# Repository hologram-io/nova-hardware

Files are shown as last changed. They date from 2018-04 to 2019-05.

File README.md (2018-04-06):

# Hologram Nova Hardware Repository

The Hologram Nova is an Open-Sourced USB Cellular Modem utilizing the [ublox SARA](https://www.u-blox.com/en/product-search/field_product_form/sara-111) family of modems.

Certified by the Open Source Hardware Association - [Certificate US000077](http://certificate.oshwa.org/certification-directory/)

We're excited to see what you'll build with these designs. If you require support for integrating these designs into your project, you can reach out to Hologram Solutions Engineering at sales@hologram.io to learn about Hologram design review services or hear about our engineering design partners.

### Additional Nova Information

 - [Nova Product Page](https://hologram.io/nova/)
 - [Nova User Manual](https://hologram.io/docs/docs/reference/nova/user-manual/)
 - [Nova Datasheet](https://hologram.io/docs/reference/nova/datasheet/)

### Additional ublox SARA Documentation

**2G/3G - U200 series**
 - [SARA-U2 System Integration Manual](https://www.u-blox.com/sites/default/files/SARA-G3-U2_SysIntegrManual_%28UBX-13000995%29_0.pdf)
 - [u-blox AT Commands Manual](https://www.u-blox.com/sites/default/files/u-blox-CEL_ATCommands_%28UBX-13002752%29.pdf)
 - [AT Command Examples for u-blox cellular modules](https://www.u-blox.com/sites/default/files/AT-CommandsExamples_AppNote_%28UBX-13001820%29.pdf)
 - [Multiplexer implementation in cellular modules](https://www.u-blox.com/sites/default/files/products/documents/MuxImplementation_ApplicationNote_%28UBX-13001887%29.pdf)
 
**LTE Cat M1/NB1 and EGPRS - R400/N400 series**

 - [SARA-R4 System Integration Manual](https://www.u-blox.com/sites/default/files/SARA-R4_SysIntegrManual_%28UBX-16029218%29.pdf)
 - [SARA-R4 AT Commands Manual](https://www.u-blox.com/sites/default/files/SARA-R4_ATCommands_%28UBX-17003787%29.pdf)

**Power-optimized NB-IoT - N200 series**

 - [SARA-N2 System Integration Manual](https://www.u-blox.com/sites/default/files/SARA-N2_SysIntegrManual_%28UBX-17005143%29.pdf)
 - [SARA-N2 AT Commands](https://www.u-blox.com/sites/default/files/SARA-N2_ATCommands_%28UBX-16014887%29.pdf)

### Additional Hologram Information

 - [BLOG Why We Open Source Hardware](https://hologram.io/open-sourcing-our-hardware/)
 - [Documentation](https://hologram.io/docs/)
 - [Forums](https://community.hologram.io/)

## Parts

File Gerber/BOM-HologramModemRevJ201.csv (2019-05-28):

LibRef | Internal PN | Quantity | Designator | Description | Footprint | Comment | MFG | MPN
ANT-A-1JB | CON-0006 | 1 | ANT_UFL |  | UFL | ANT-A-1JB | Amphenol | A-1JB
CAP0.1uF_0402 | CAP-0004 | 3 | C2, C6, C48 | CAPACITOR, American symbol | CAP0402 | 0.1 uF | MURATA | GRM155R61C104KA88D
CAP2.2uF_0603 | CAP-0002 | 1 | C11 | Ceramic Capacitor SMD | CAP0603 | 2.2 uF | SAMSUNG | CL10A225MQ8NNNC
CAP10nF_0402 | CAP-0016 | 3 | C1, C5, C39 | CAPACITOR, American symbol | CAP0402 | 10 nF | MURATA | GRM155R71C103KA01D
CAP10uF_0603 | CAP-0007 | 1 | C34 | Ceramic Capacitor SMD | CAP0603 | 10 uF | Murata | GRM188R60J106ME84D
CAP15pF_0402 | CAP-0011 | 3 | C4, C8, C46 | CAPACITOR, American symbol | CAP0402 | 15 pf | AVX/ELCO | 04025A150JAT2A
CAP22uF_0603 | CAP-0008 | 3 | C36, C37, C38 | Ceramic Capacitor SMD | CAP0603 | 22 uF | MURATA | GRM188R60J226MEA0D
CAP47pf_0402 | CAP-0010 | 4 | C41, C42, C44, C45 | CAPACITOR, American symbol | CAP0402 | 47 pF | AVX | 04025A470JAT2A
CAP56pF_0402 | CAP-0009 | 3 | C3, C7, C40 | CAPACITOR, American symbol | CAP0402 | 56 pf | KEMET | C0402C560J5GACTU
CAP330uF_1210P | CAP-0012 | 3 | C47, C49, C50 | Capacitor | CAP1210POL | 330uF | AVX | F950J337MBAAQ2
FerriteBead_120ohm_3A | IND-0005 | 1 | L7 |  | RES0603 | FerriteBead 120ohm, 3A | Murata | BLM18KG121TN1D
INDUCTOR_1UH_XFL4020-102MEC | IND-0003 | 1 | L5 |  | COILCRAFT_XFL4020 | 1uH | Coilcraft | XFL4020-102MEC
LED_0402_VLMB | DIO-0007 | 1 | D1 | LED, Vishay Blue 0402 | LED_0402_VISHAY_VLMB | LED_0402_VLMB | VISHAY | VLMB1500-GS08
LED_0402_VLMS | DIO-0008 | 1 | D2 | LED, Vishay Red 0402 | LED_0402_VISHAY_VLMS | LED_0402_VLMS | VISHAY | VLMS1500-GS08
PESD_14V | DIO-0009 | 7 | D3, D4, D5, D6, D7, D8, D9 | DIODE,ZENER VOLTAGE SUPPRESSOR,+/-14V | PESD_0402 |  | Littlefuse | PESD0402-140
RES0R_0603 | RES-0020 | 1 | L1 | Resistor, 0 ohm, 0603 case | RES0603 | 0 ohm | YAEGO | RC0603JR-070RL
RES1M_0402 | RES-0014 | 1 | R13 | Resistor, 1M ohm, 0402 case, 1% | RES0402 | 1M | YAEGO | RC0402FR-071ML
RES3K_0402 | RES-0019 | 2 | R3, R5 | Resistor, 3K ohm, 0402 case, 1% | RES0402 | 3k | YAEGO | RC0402FR-073KL
RES10K_0402 | RES-0008 | 4 | R4, R6, R7, R8 | Resistor, 10k ohm, 0402 | RES0402 | 10K | YAEGO | RC0402JR-0710KL
RES22R_0402 | RES-0016 | 2 | R1, R2 | Resistor, 22 ohm, 0402 case, 1% | RES0402 | 22 | YAEGO | RC0402FR-0722RL
RES100K_0402 | RES-0003 | 1 | R51 | Resistor, 100k ohm, 0402 | RES0402 | 100K | PANASONIC | ERJ-2GEJ104X
RES150K_0402 | RES-0004 | 1 | R12 | Res, 150k ohm, 0402 case, 1% | RES0402 | 150k | YAEGO | RC0402FR-07150KL
RES470R_0402 | RES-0006 | 1 | R9 | Resistor, 470 ohm, 0402 case, 1% | RES0402 | 470 | PANASONIC | ERJ-2GEJ471X
SARA-U2XX | IC-0007 | 1 | U16 |  | SARA | SARA-U2XX | U-BLOX | SARA-U201-03B
SIM_CARD_NANO | CON-0007 | 1 | SIM1 |  | SIM_CARD_NANO | SIM_CARD_NANO | GLOBAL CONNECTOR TECHNOLOGY | SIM8050-6-0-14-01-A
TPS63020 | IC-0013 | 1 | U2 | Regulator, Boost Buck, 3A | QFN-14-POWERPAD3X4DSJ | TPS63020 | TI | TPS63020DSJ
TSTR_3904_SOT23 | IC-0014 | 4 | Q1, Q2, Q3, Q4 | TSTR,NPN 3904, SOT23 | SOT23 |  | ON Semiconductor | MMBT3904LT1G
USB_A_PLUG_MOLEX_0480372200 | CON-0008 | 1 | J1 | Connector, USB A, Plug, 0480372200 | USB_A_PLUG_MOLEX_0480372200 - clipped_copper | USB_A_PLUG_MOLEX_0480372200 | MOLEX | 480372200

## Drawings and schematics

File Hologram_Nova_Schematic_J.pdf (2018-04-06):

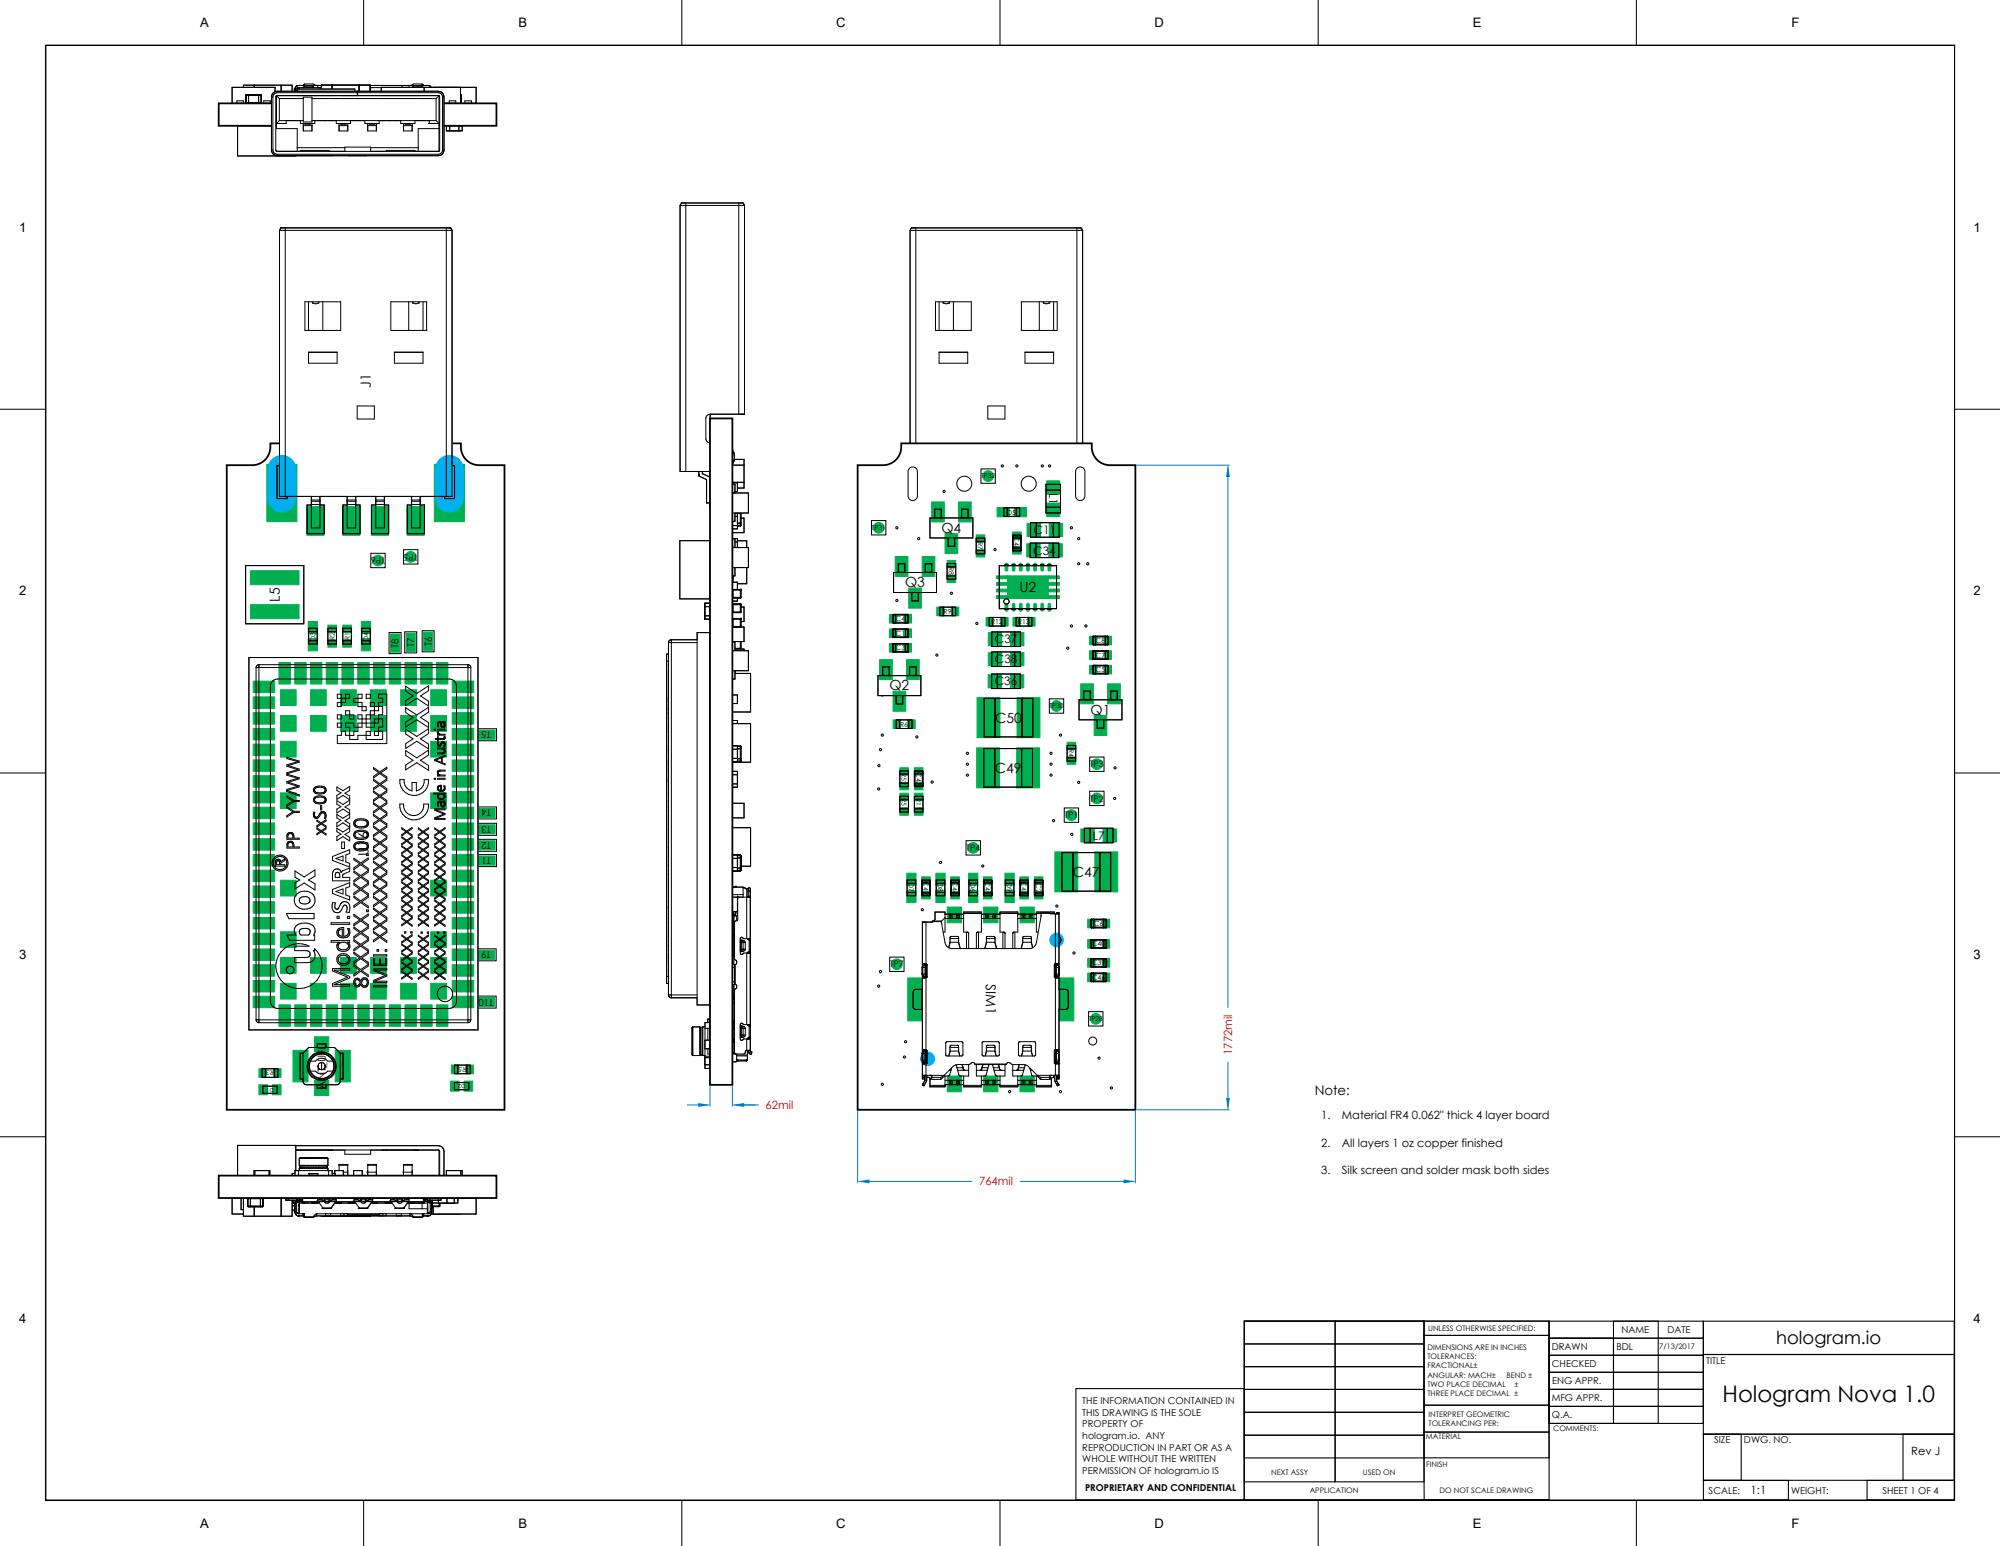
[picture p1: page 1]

1. Material FR4 0.062" thick 4 layer board

2. All layers 1 oz copper finished

3. Silk screen and solder mask both sides

UNLESS OTHERWISE SPECIFIED: | | NAME | DATE 7/13/2017 | hologram.io
DIMENSIONS ARE IN INCHES TOLERANCES: FRACTIONAL± ANGULAR: MACH± BEND ± TWO PLACE DECIMAL ± THREE PLACE DECIMAL ± | DRAWN | BDL

CHECKED | | | TITLE Hologram Nova 1.0
ENG APPR.

THE INFORMATION CONTAINED IN THIS DRAWING IS THE SOLE PROPERTY OF hologram.io. ANY REPRODUCTION IN PART OR AS A WHOLE WITHOUT THE WRITTEN PERMISSION OF hologram.io IS PROPRIETARY AND CONFIDENTIAL | | | MFG APPR.

INTERPRET GEOMETRIC TOLERANCING PER: | Q.A.

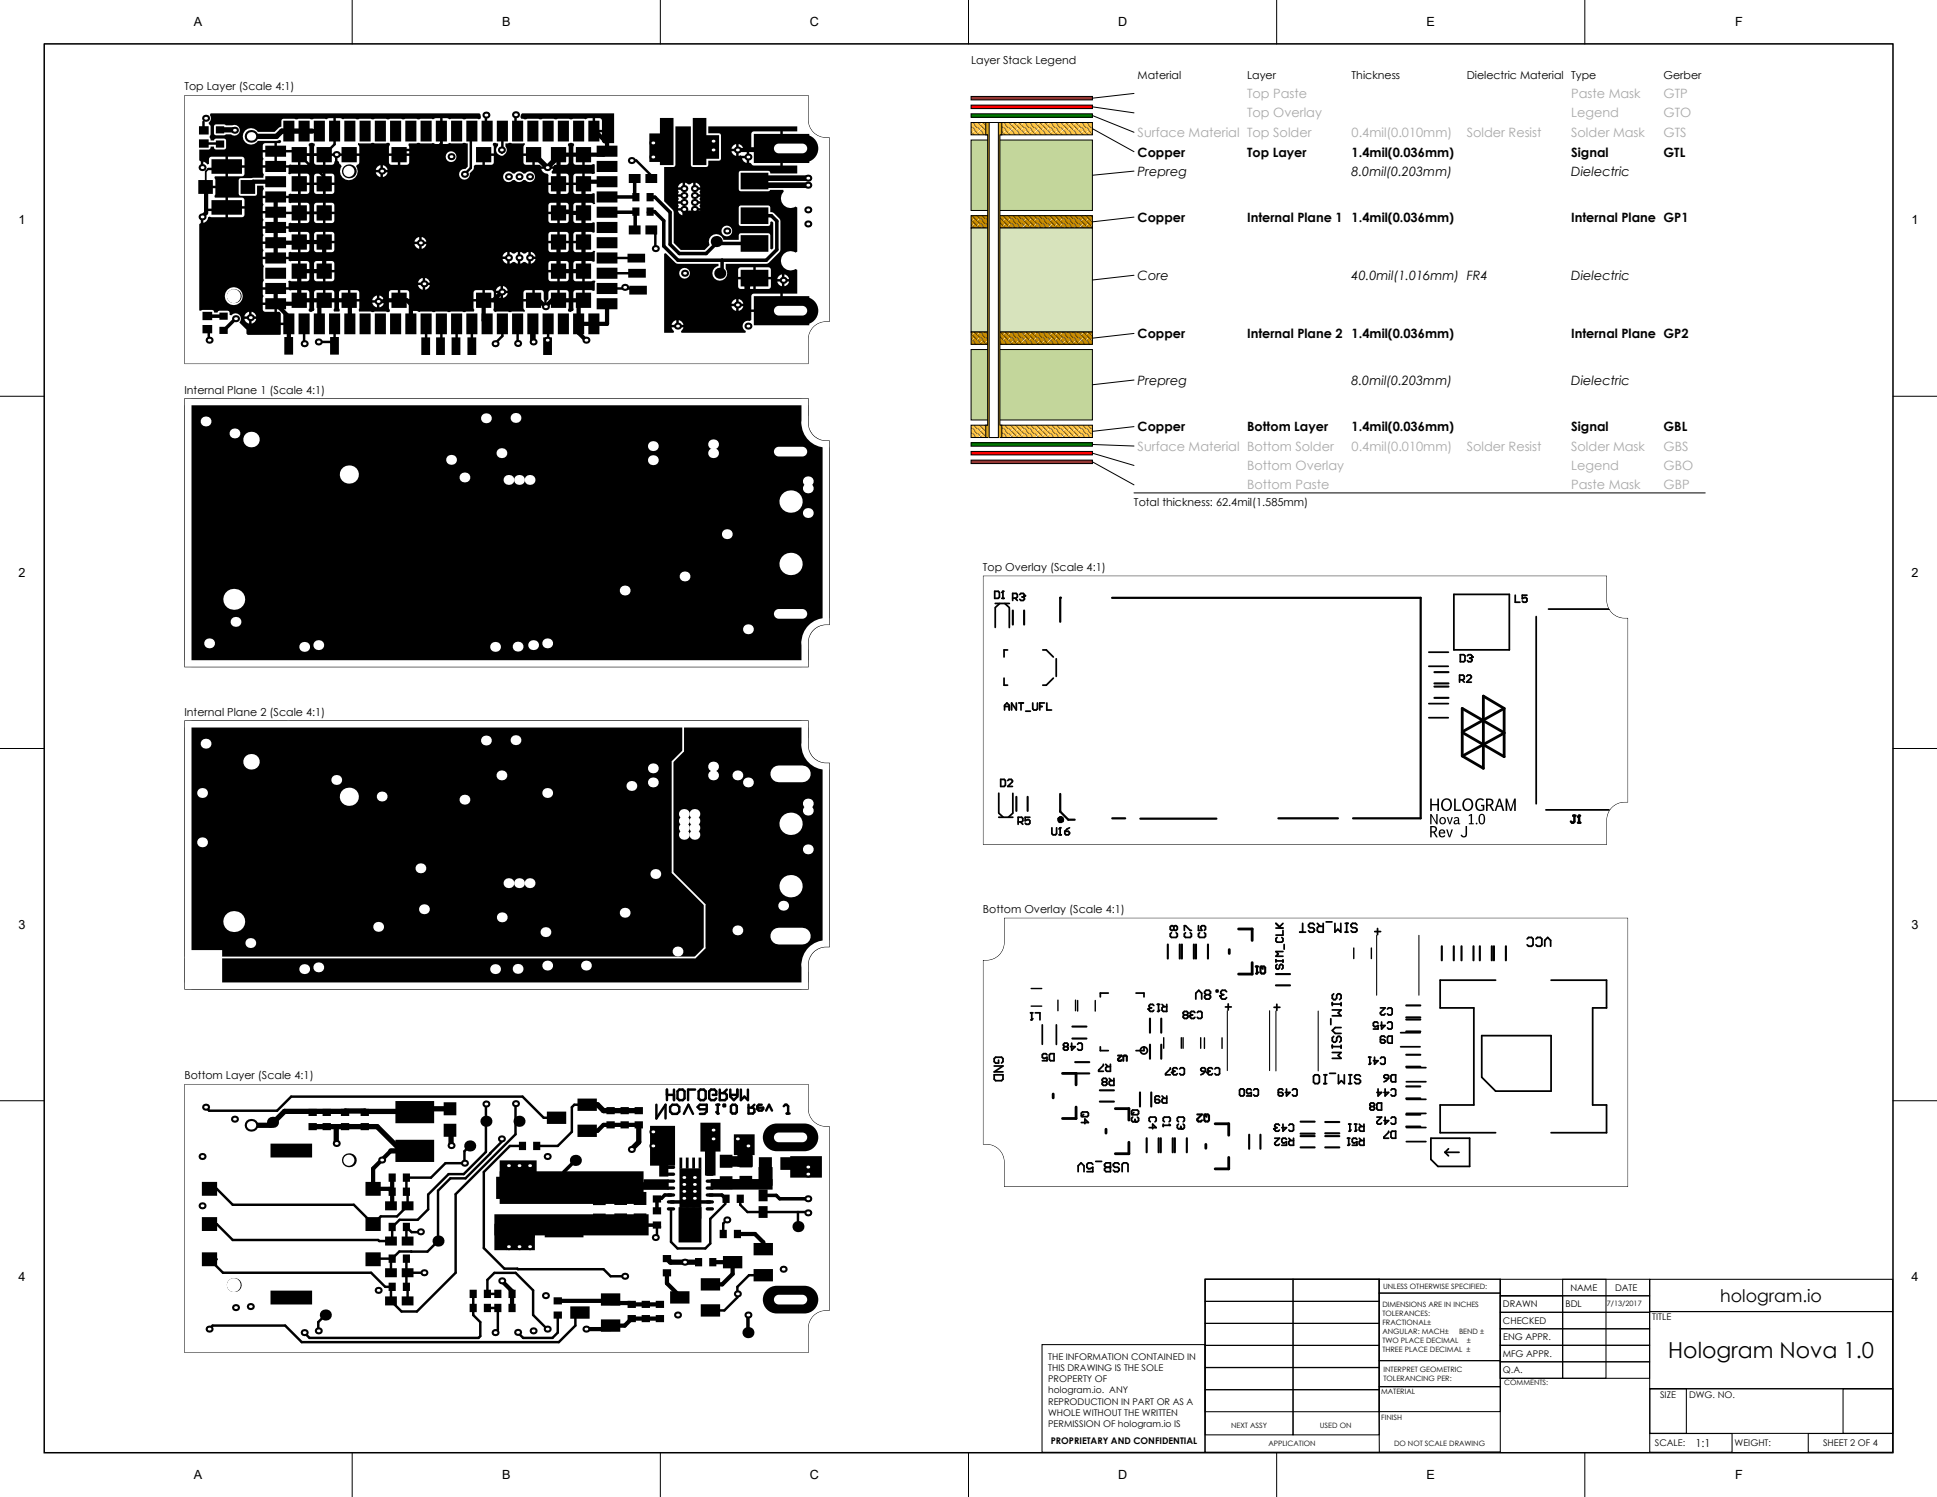
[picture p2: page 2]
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

CHECKED | | | TITLE Hologram Nova 1.0
ENG APPR.

THE INFORMATION CONTAINED IN THIS DRAWING IS THE SOLE | | | MFG APPR.

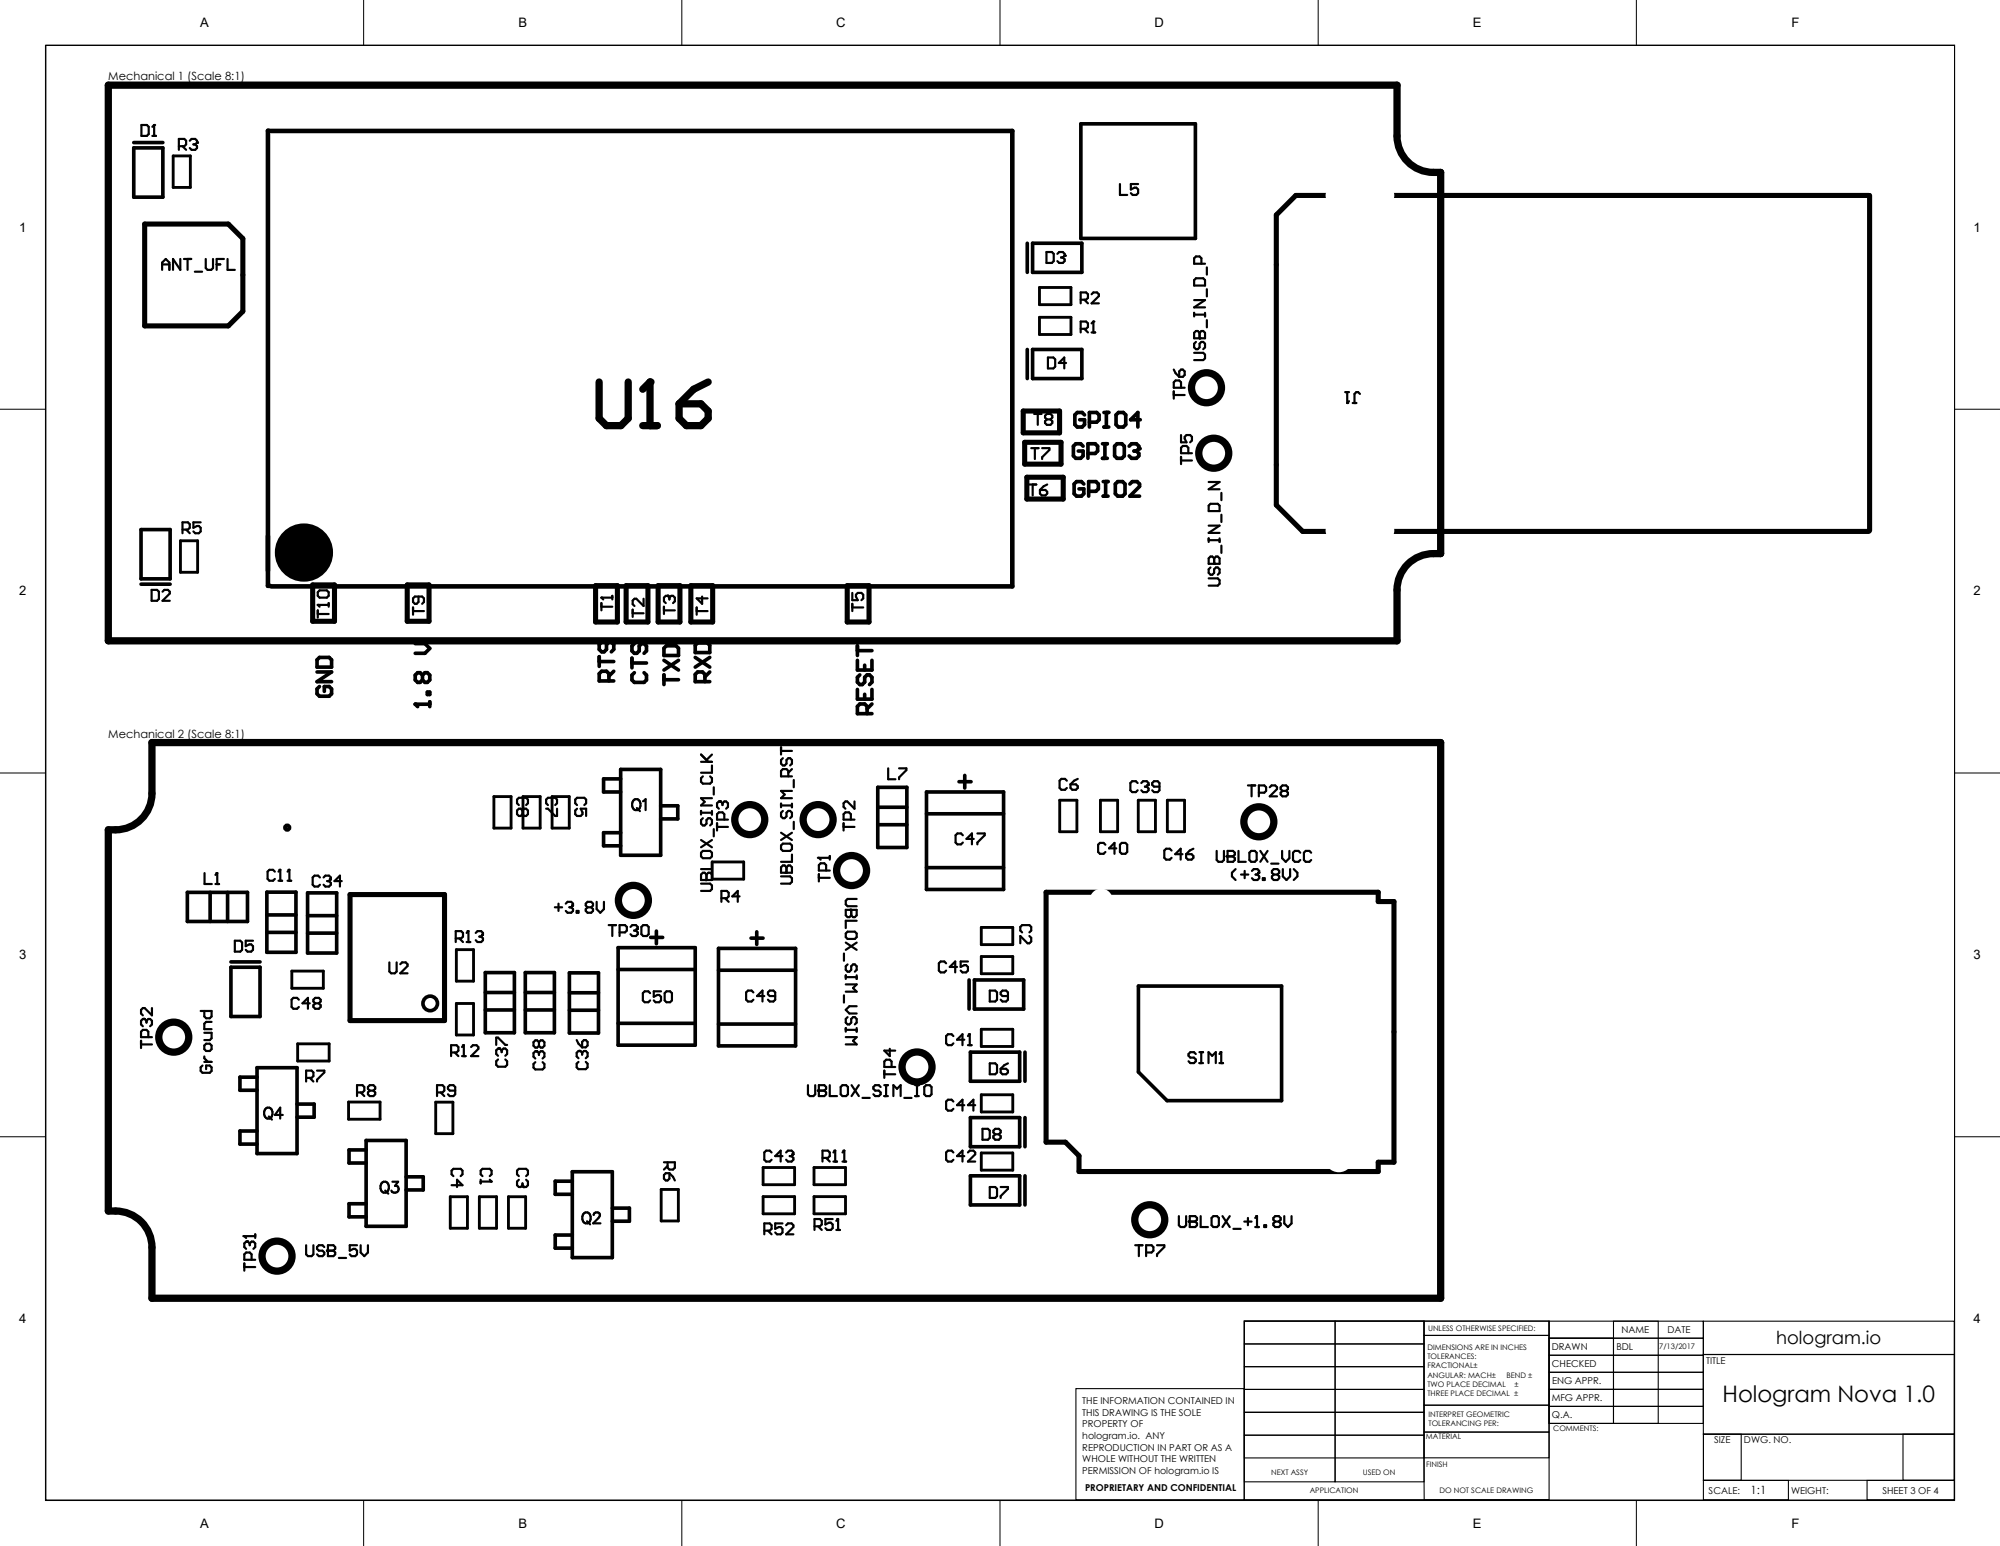
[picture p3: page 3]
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

CHECKED | | | TITLE Hologram Nova 1.0
ENG APPR.

THE INFORMATION CONTAINED IN THIS DRAWING IS THE SOLE | | | MFG APPR.

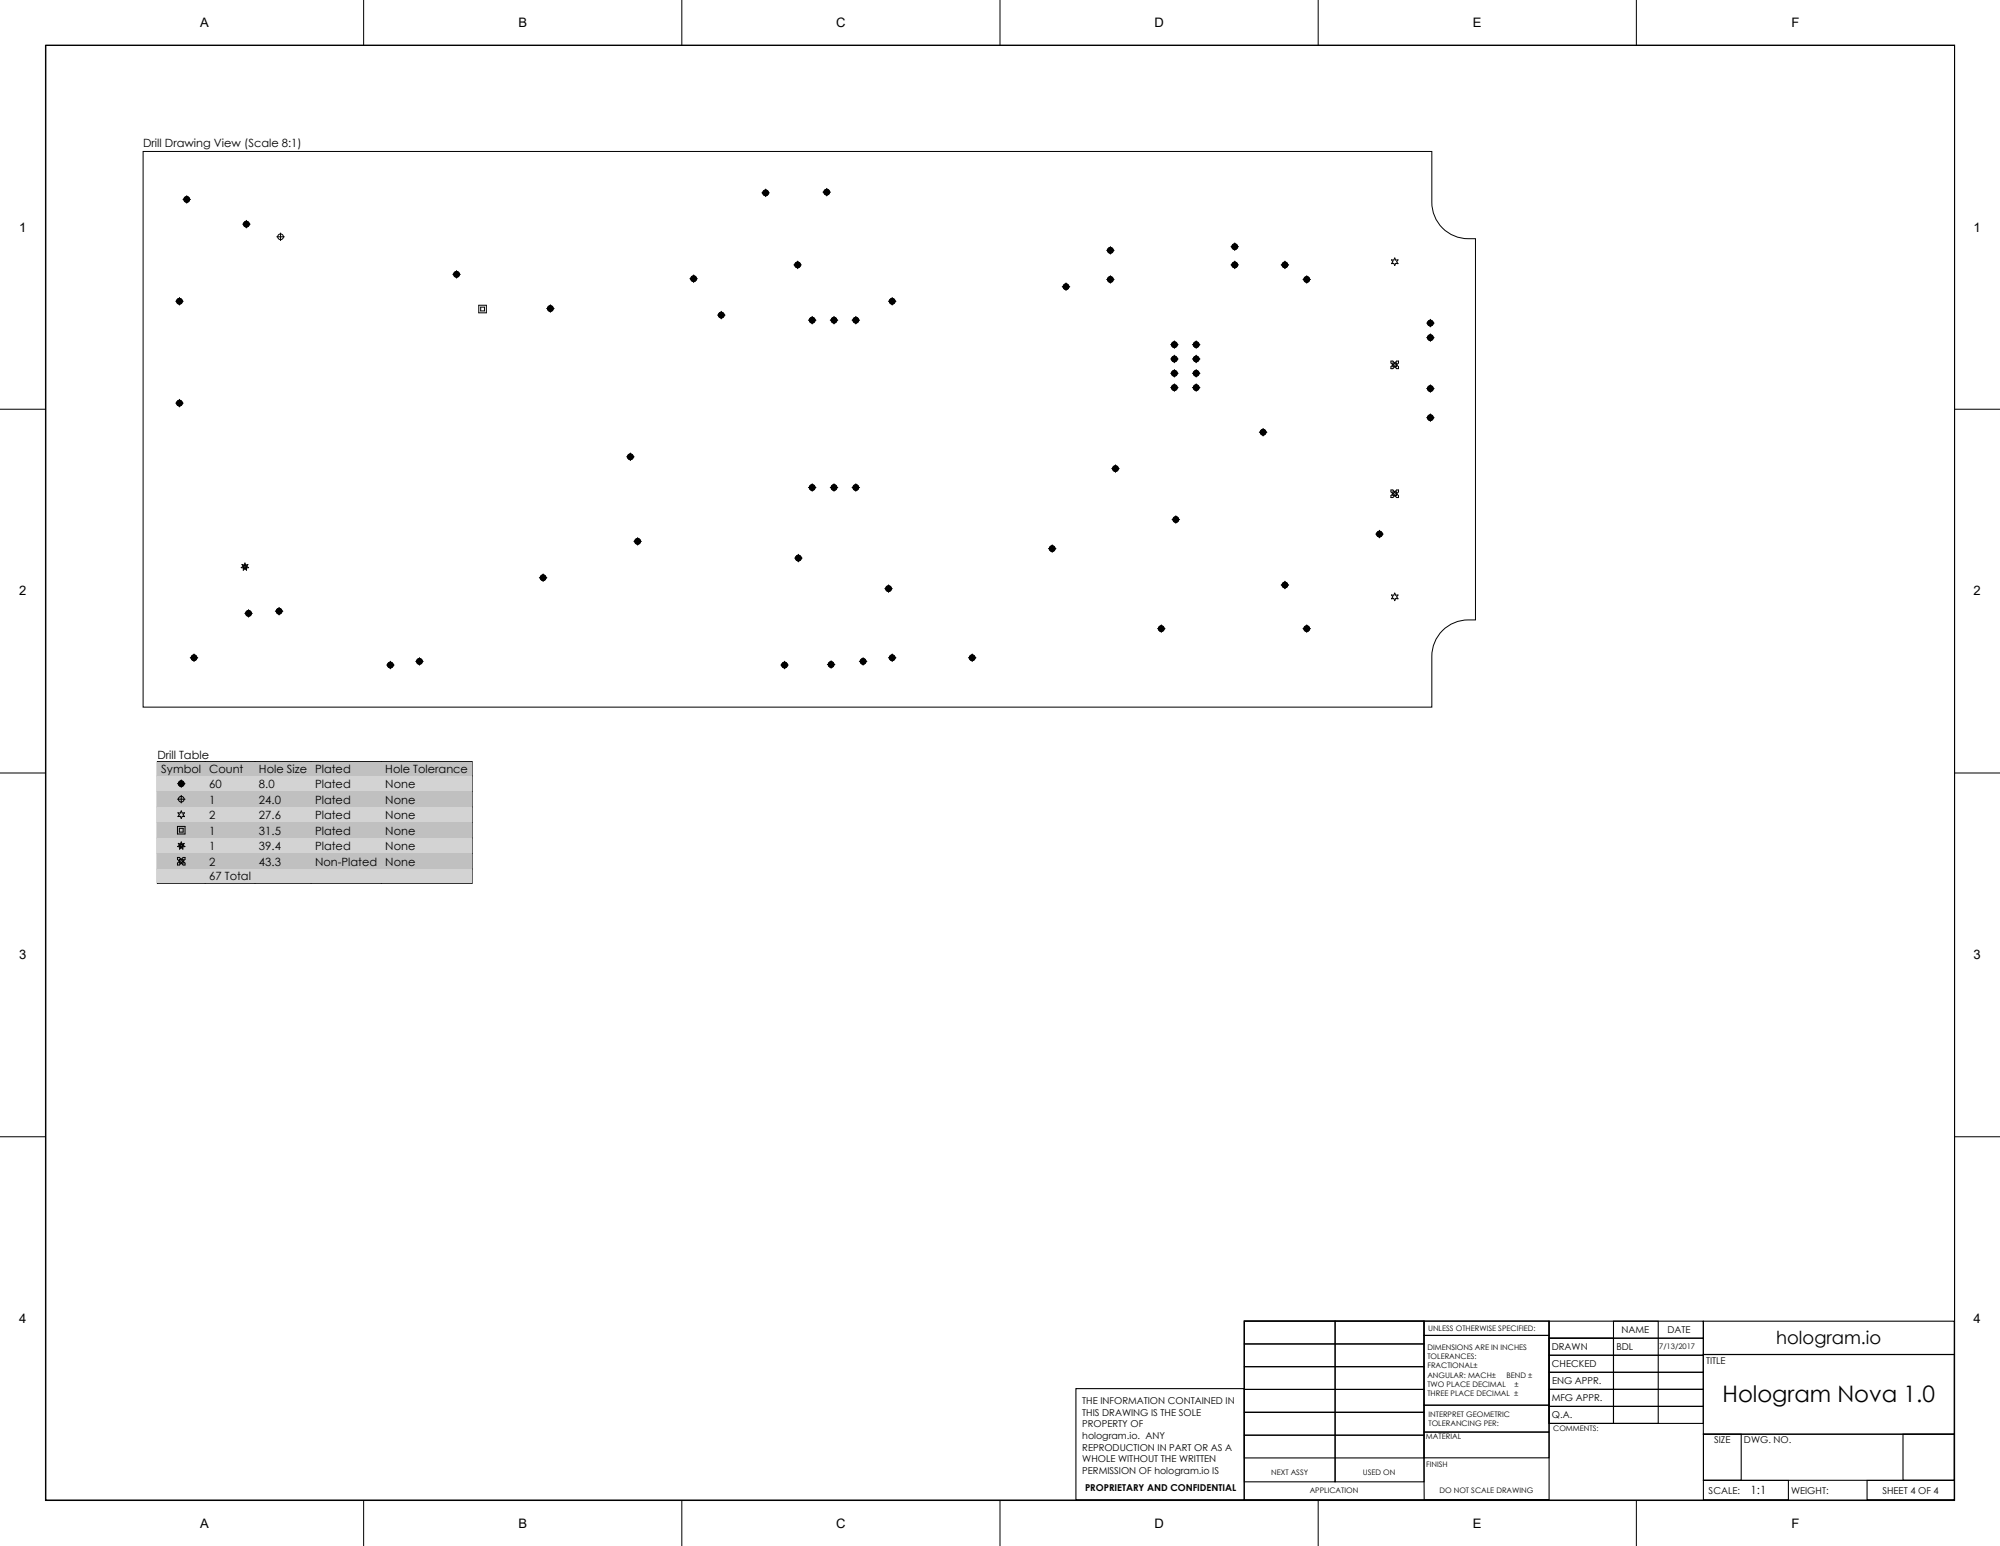
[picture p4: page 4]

Drill Drawing View (Scale 8:1)

Symbol | Count | Hole Size | Plated | Hole Tolerance

60 | 8.0 | Plated | None
1 | 24.0 | Plated | None
2 | 27.6 | Plated | None
1 | 31.5 | Plated | None
1 | 39.4 | Plated | None
2 | 43.3 | Non-Plated | None
67 Total

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

CHECKED | | | TITLE Hologram Nova 1.0
ENG APPR.

THE INFORMATION CONTAINED IN THIS DRAWING IS THE SOLE | | | MFG APPR.

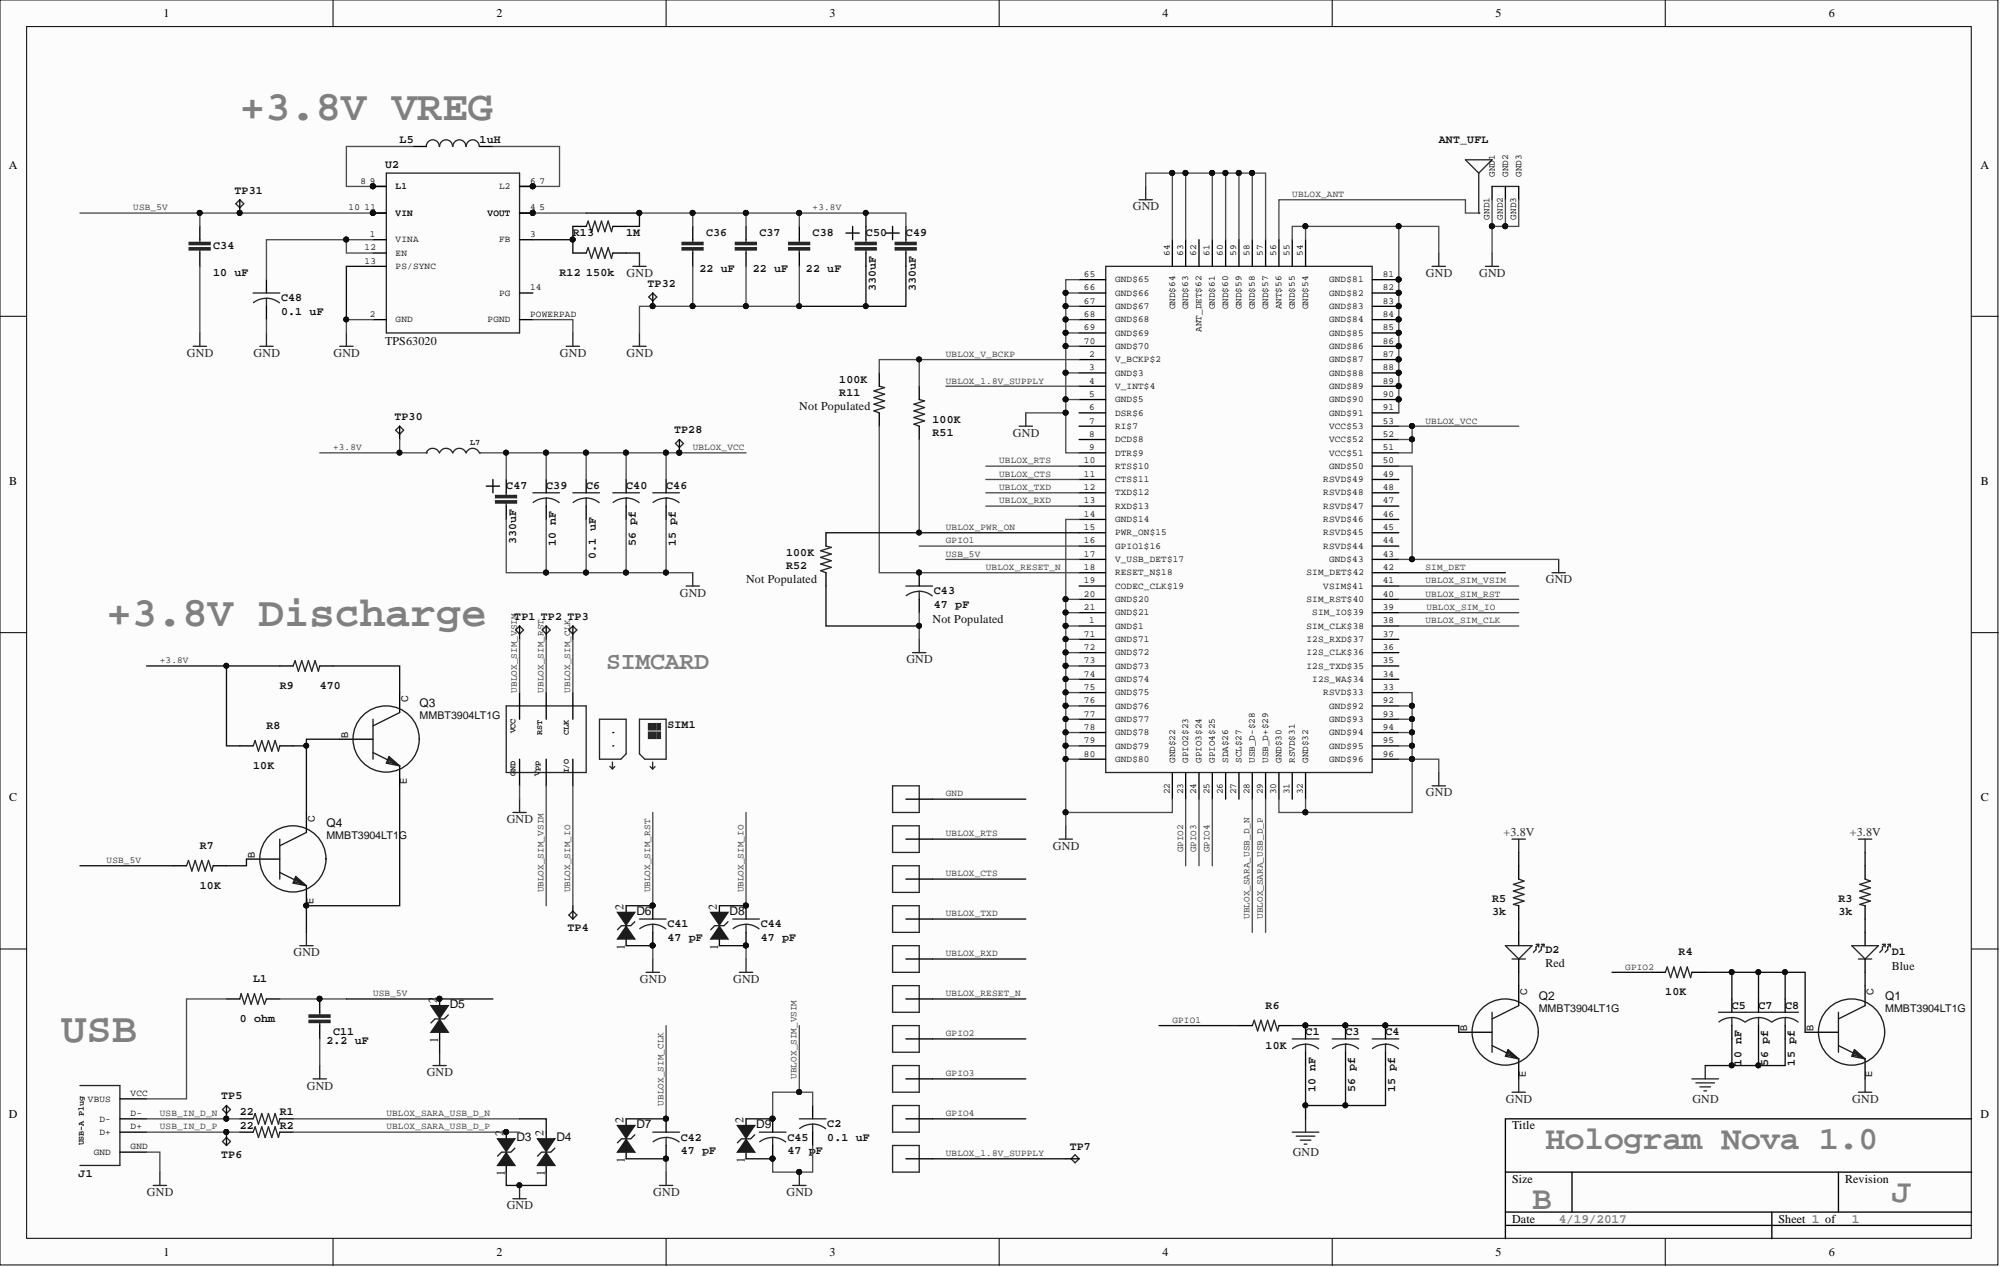
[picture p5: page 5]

6 6 | | 8 2
6 7 | | | 8 3
6 8 | | | 8 4

6 9 | | | 8 5
7 0 | | | 8 6
2 | | | 8 7

3 | 8 8
4 5 | | 8 9

6 | | 9 1

7 6 | 9 2
7 7 | 9 3
7 8 | 9 4

7 9 | 9 5
8 0 | 9 6

Size | | Rev i s i o n J

Dat e 4 / 1 9 / 2 0 1 7 | Sheet 1 o f 1

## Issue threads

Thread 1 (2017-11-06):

Improper spelling

Jolley71717, 2017-11-06:
when a PPP session exists and the user executes the code `sudo hologram modem disconnect` the user is presented with the following:
`Checking for existing PPP sessions
Found existing PPP session on pid: [the pid that is found]`
The error shows up on the next line:
`Kiiing pid [the pid that is found] now`

tzhenghao, 2017-11-06:
Hey @Jolley71717 , thanks for pointing this out. I already have a patch up to address this. Stay tuned for the next release!

tzhenghao, 2017-11-20:
@Jolley71717 We addressed this in the latest Python SDK v0.7.0 release, so I'm gonna close this.

Closed 2017-11-20.

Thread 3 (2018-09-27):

Can't use UART without cutting traces

tve, 2018-09-27:
I'm very grateful for the fact that you provided pads to hook up to the UART of the Sara-R404 but unfortunately it can't be used without cutting traces. The Vusb has to be cut to the R404 else it doesn't even turn the UART on. This means one has to feed the 3.8V rail directly (which is OK per-se) but that means one has to cut the trace at the output of the regulator and also disconnect the "3.8V discharge" circuit. It would be nice if you could provide a solder jumper or two on a future rev so this type of surgery can be done reasonably easily, at least as easily as soldering stuff to the UART pads.

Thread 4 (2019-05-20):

R410 BOM doesn't match schematic and PCB

eprast22, 2019-05-20:
Hello,

Regarding the Hologram Nova Gerbers:

The following components are listed on the schematic and on the PCB, I don't see these components on the BOM.

L1, C1, C3, C4, C8, C7, C5, D6, D7, D8, D9.

Can someone help me understand why these are missing? Are these components no longer needed.

Several of these capacitors are used for decoupling and may be optional. But L1 is required as 0 ohm resistor to receive 5V from USB.

Additionally, there are components on the BOM (R11, R51, C43) that are DNI (not populated) on the schematic. Are these components required?

If anyone knows this would be very helpful! Thank you.

rbalik, 2019-05-28:
Hey, the correct BOM is now in the repo. I'm going to close this, but feel free to open a new issue or post on our forum with any questions.

Closed 2019-05-28.

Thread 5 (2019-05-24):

R410 PWR_ON

jsuffolk, 2019-05-24:
UBlox documentation describes a sequence for activating R410 via PWR_ON signal low. Nova schematic shows PWR_ON linked to pin 2, an undocumented reserved pin. Does anybody know if this is an undocumented way to achieve PWR on automatically when power is applied to the R410 device? Or is there something amiss with the schematic?

rbalik, 2019-05-24:
Ublox confirmed with us that our method is ok before we went to production. I think the only downside to doing it this way is that if you power it off with CPWROFF then you can't turn it back on without a full power cycle but that's not really a problem for this use case.

rbalik, 2019-05-24:
Oh also note that the schematic is for the U201. We place a few things a little differently for the R410 (same PCB though). See BOM for more information

jsuffolk, 2019-05-26:
Thanks, this is pretty helpful. Looking at the R410 Nova board I have, looks like the R51, R11, and C43 are not populated, but the R52 is (presumably the 100K resistor to ground as shown in the schematic). Can you confirm that this is accurate?

rbalik, 2019-05-28:
I just added the actual BOM for the R410 into this repo so you should be able to see exactly what you need now. I'm gonna go ahead and close this but feel free to open a new issue or post on our forum ( https://community.hologram.io/ ) if you have any more questions.

Closed 2019-05-28.
